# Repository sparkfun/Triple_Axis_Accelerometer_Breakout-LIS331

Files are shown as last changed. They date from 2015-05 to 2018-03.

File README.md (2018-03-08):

SparkFun Triple Axis Accelerometer Breakout - LIS331
========================================

SparkFun Triple Axis Accelerometer Breakout - LIS331

[*SparkFun Triple Axis Accelerometer Breakout - LIS331 (SEN-10345)*](https://www.sparkfun.com/products/10345)

 This is a breakout board for the ultra low-power LIS331HH three axis linear accelerometer. 
 The device has a digital I2C/SPI serial interface which makes it ideal for using in embedded applications. 
 All major pins are broken out to 0.1" spaced headers. It also includes two mounting holes as well.
 
Repository Contents
-------------------

* **/Firmware** - Example code 
* **/Hardware** - Eagle design files (.brd, .sch)
* **/Production** - Production panel files (.brd)

Documentation
--------------
* **[SparkFun Fritzing repo](https://github.com/sparkfun/Fritzing_Parts)** - Fritzing diagrams for SparkFun products.
* **[SparkFun 3D Model repo](https://github.com/sparkfun/3D_Models)** - 3D models of SparkFun products. 
* **[Project Tutorial](https://learn.sparkfun.com/tutorials/raspberry-pi-zero-helmet-impact-force-monitor)** - Project tutorial using the LIS331 on a Raspberry Pi. The code used in the project uses Python and linked in a [different GitHub repository](https://github.com/jenfoxbot/ImpactForceMonitor). 

License Information
-------------------
This product is _**open source**_! 

The **hardware** is released under [Creative Commons ShareAlike 4.0 International](https://creativecommons.org/licenses/by-sa/4.0/).

The **code** is beerware; if you see me (or any other SparkFun employee) at the local, and you've found our code helpful, please buy us a round!

Please use, reuse, and modify these files as you see fit. Please maintain attribution to SparkFun Electronics and release anything derivative under the same license.

Distributed as-is; no warranty is given.

- Your friends at SparkFun.

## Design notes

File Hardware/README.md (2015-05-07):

SparkFun <PRODUCT NAME> Design Files
=====================================

The .sch and .brd files hare are Eagle CAD schematic and PCB design files from SparkFun Electronics.
A freeware version of Eagle can be found [here](http://www.cadsoftusa.com/download-eagle/freeware/). 

License
---------
This product is open source! 
The hardware is released under [Creative Commons ShareAlike 4.0 International](https://creativecommons.org/licenses/by-sa/4.0/).

Please use, reuse, and modify these files as you see fit. Please maintain attribution to SparkFun Electronics and release anything derivative under the same license.

Distributed as-is; no warranty is given.

- Your friends at SparkFun.

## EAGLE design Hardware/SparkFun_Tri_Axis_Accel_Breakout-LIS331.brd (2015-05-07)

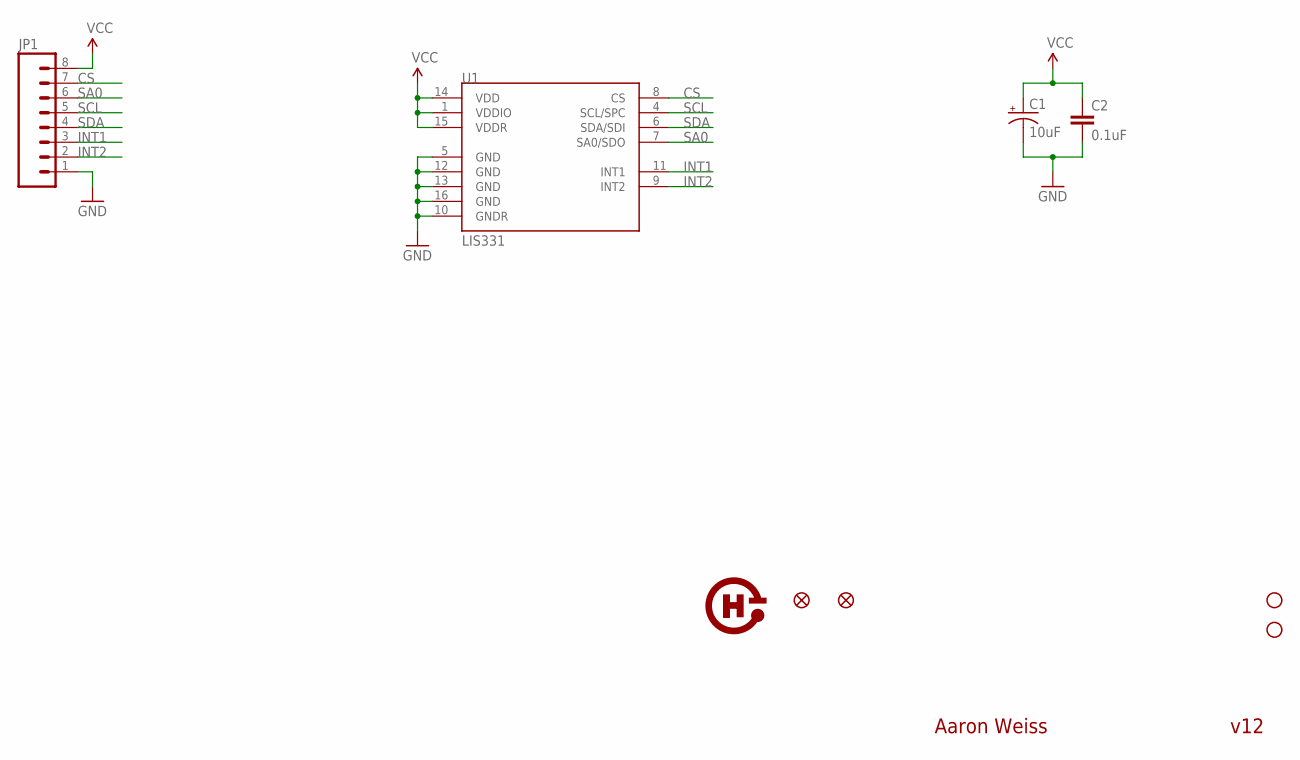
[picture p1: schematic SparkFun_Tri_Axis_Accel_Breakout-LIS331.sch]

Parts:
C1: 10uF; EIA3216
C2: 0.1uF; 0402-CAP
JP1: M08; 1X08
JP3, JP4: STAND-OFF
JP5, JP6: FIDUCIAL1X2; FIDUCIAL-1X2
U1: LIS331; LGA16-3MM
U$1: OSHW-LOGO-SMALL

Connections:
CS: JP1.7, U1.8 (CS)
GND: C1.C (-), C2.2, JP1.1, U1.5 (GND), U1.10 (GNDR), U1.12 (GND), U1.13 (GND), U1.16 (GND)
INT1: JP1.3, U1.11 (INT1)
INT2: JP1.2, U1.9 (INT2)
SA0: JP1.6, U1.7 (SA0/SDO)
SCL: JP1.5, U1.4 (SCL/SPC)
SDA: JP1.4, U1.6 (SDA/SDI)
VCC: C1.A (+), C2.1, JP1.8, U1.1 (VDDIO), U1.14 (VDD), U1.15 (VDDR)

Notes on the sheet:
v12
Aaron Weiss

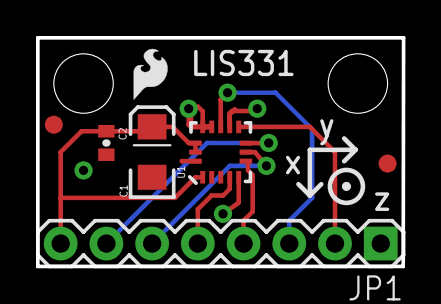
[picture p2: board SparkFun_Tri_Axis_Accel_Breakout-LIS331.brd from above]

Board: 2 copper layers, 20.3 x 12.7 mm, 10 parts (1 on the bottom side), 8 nets.

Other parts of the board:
JP2: LOGO-SFESK; SFE-LOGO-FLAME

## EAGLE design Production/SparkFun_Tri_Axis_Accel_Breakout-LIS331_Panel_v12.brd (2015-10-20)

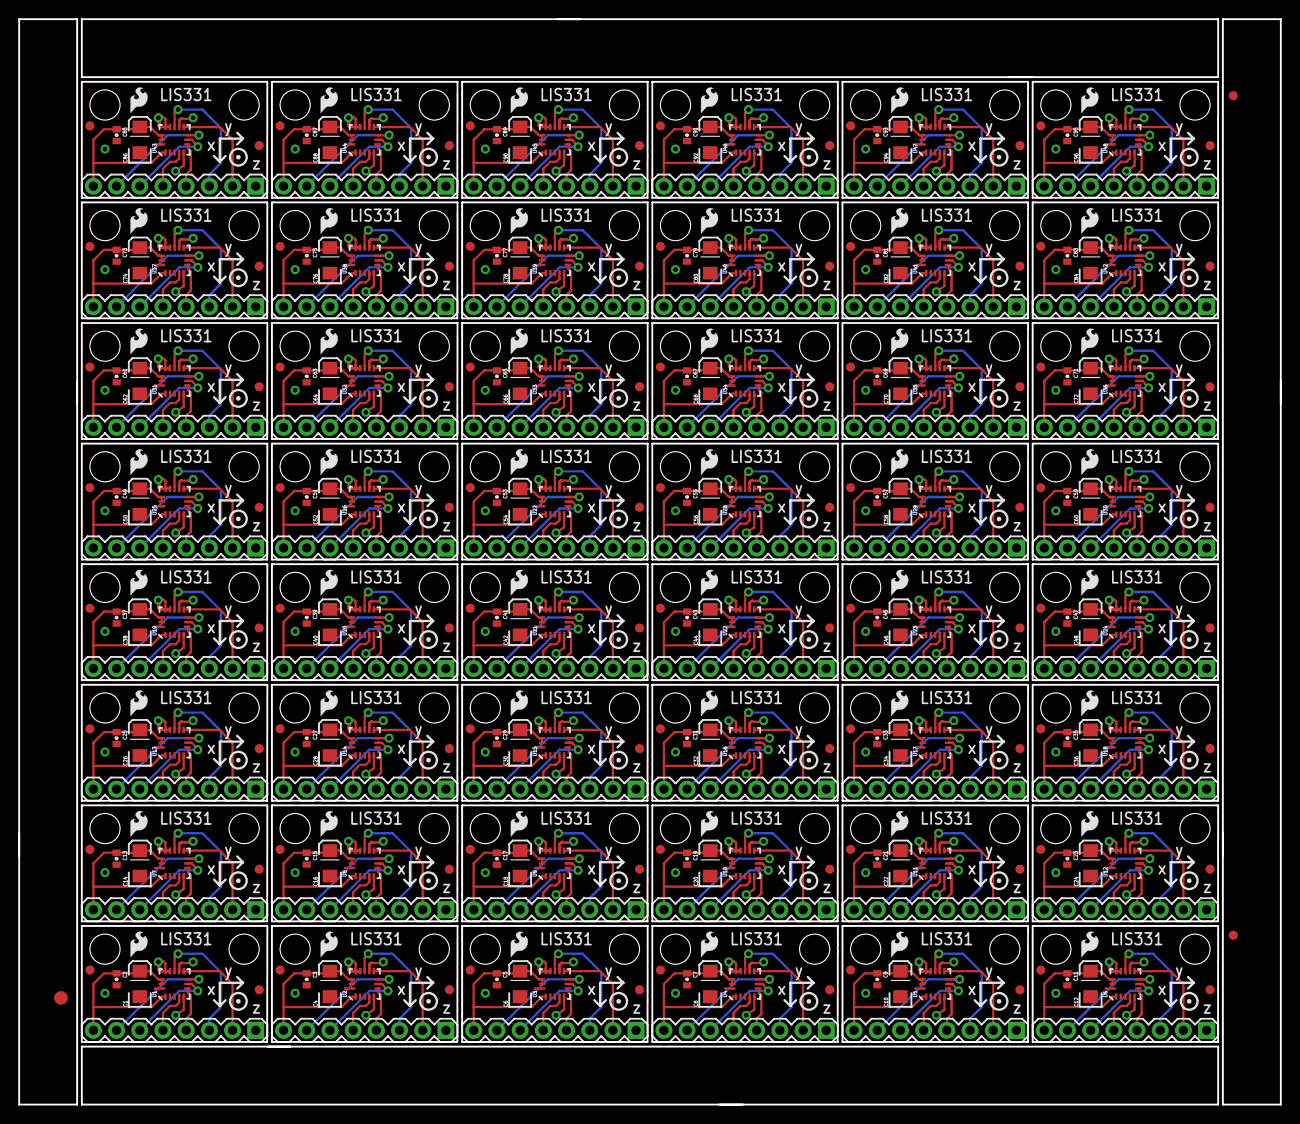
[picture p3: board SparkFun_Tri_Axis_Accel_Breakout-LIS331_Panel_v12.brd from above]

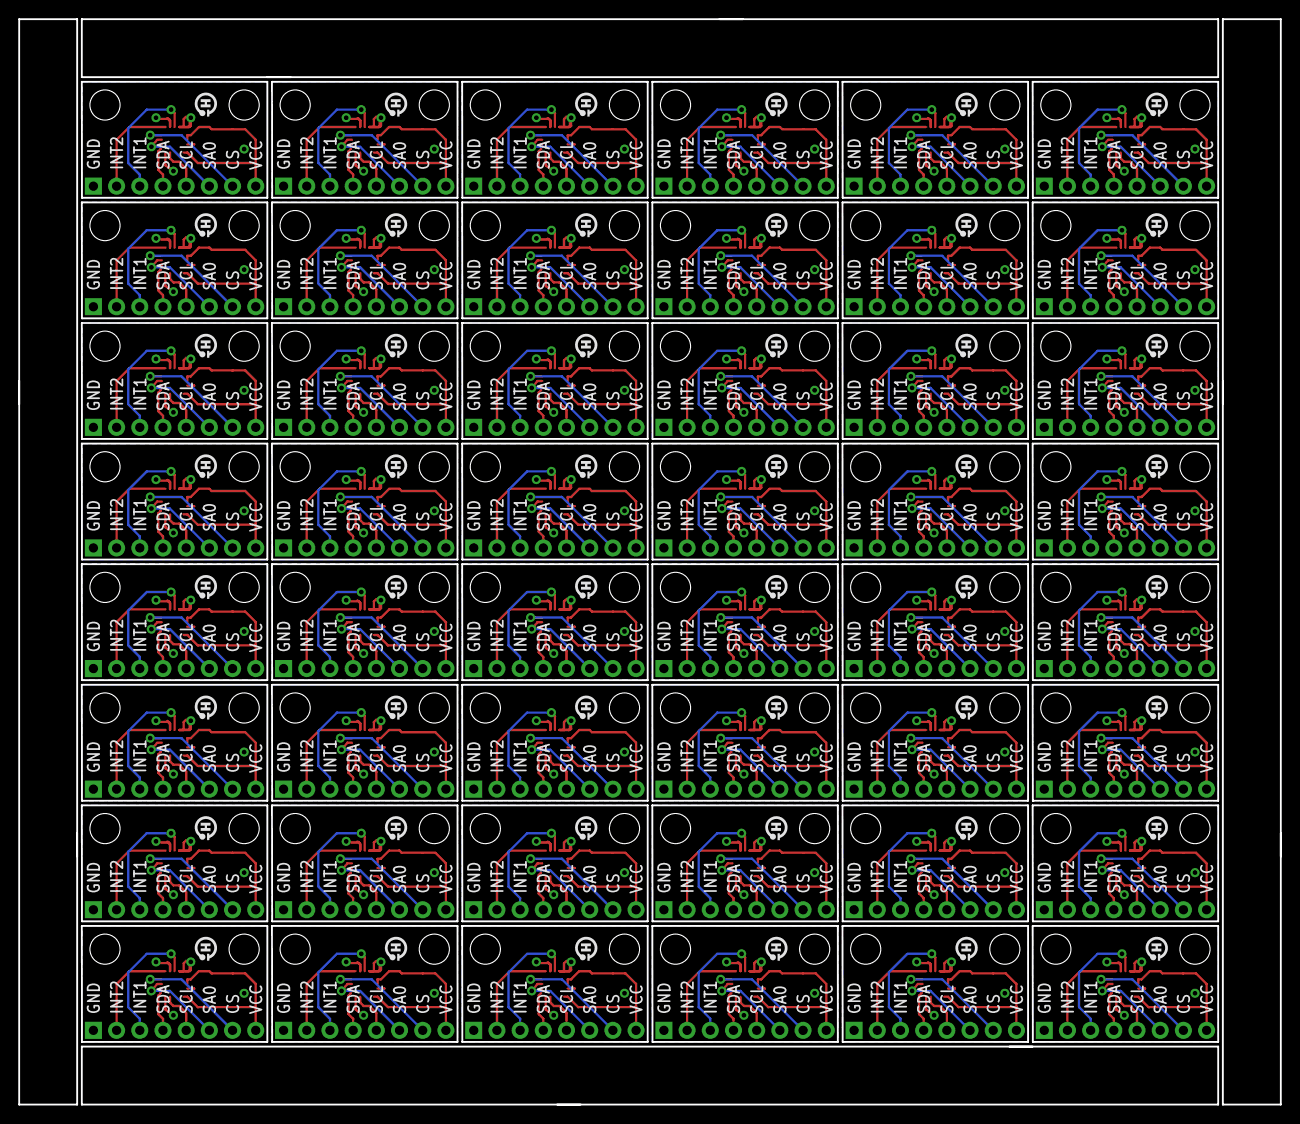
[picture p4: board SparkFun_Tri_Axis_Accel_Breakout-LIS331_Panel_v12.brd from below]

Board: 2 copper layers, 138.2 x 118.9 mm, 483 parts (48 on the bottom side), 384 nets.

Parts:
C1, C4, C6, C8, C10, C12, C14, C16, C18, C20, C22, C24, C26, C28, C30, C32, C34, C36, C38, C40, C42, C44, C46, C48, C50, C52, C54, C56, C58, C60, C62, C64, C66, C68, C70, C72, C74, C76, C78, C80, C82, C84, C86, C88, C90, C92, C94, C96: 10uF; EIA3216
C2, C3, C5, C7, C9, C11, C13, C15, C17, C19, C21, C23, C25, C27, C29, C31, C33, C35, C37, C39, C41, C43, C45, C47, C49, C51, C53, C55, C57, C59, C61, C63, C65, C67, C69, C71, C73, C75, C77, C79, C81, C83, C85, C87, C89, C91, C93, C95: 0.1uF; 0402-CAP
E$1: FIDUCIAL-1.5X3
E$5, E$6: FIDUCIAL-1X2
JP1, JP8, JP14, JP20, JP26, JP32, JP38, JP44, JP50, JP56, JP62, JP68, JP74, JP80, JP86, JP92, JP98, JP104, JP110, JP116, JP122, JP128, JP134, JP140, JP146, JP152, JP158, JP164, JP170, JP176, JP182, JP188, JP194, JP200, JP206, JP212, JP218, JP224, JP230, JP236, JP242, JP248, JP254, JP260, JP266, JP272, JP278, JP284: 1X08
JP2, JP7, JP13, JP19, JP25, JP31, JP37, JP43, JP49, JP55, JP61, JP67, JP73, JP79, JP85, JP91, JP97, JP103, JP109, JP115, JP121, JP127, JP133, JP139, JP145, JP151, JP157, JP163, JP169, JP175, JP181, JP187, JP193, JP199, JP205, JP211, JP217, JP223, JP229, JP235, JP241, JP247, JP253, JP259, JP265, JP271, JP277, JP283: LOGO-SFESK; SFE-LOGO-FLAME
JP3, JP4, JP9, JP10, JP15, JP16, JP21, JP22, JP27, JP28, JP33, JP34, JP39, JP40, JP45, JP46, JP51, JP52, JP57, JP58, JP63, JP64, JP69, JP70, JP75, JP76, JP81, JP82, JP87, JP88, JP93, JP94, JP99, JP100, JP105, JP106, JP111, JP112, JP117, JP118, JP123, JP124, JP129, JP130, JP135, JP136, JP141, JP142, JP147, JP148, JP153, JP154, JP159, JP160, JP165, JP166, JP171, JP172, JP177, JP178, JP183, JP184, JP189, JP190, JP195, JP196, JP201, JP202, JP207, JP208, JP213, JP214, JP219, JP220, JP225, JP226, JP231, JP232, JP237, JP238, JP243, JP244, JP249, JP250, JP255, JP256, JP261, JP262, JP267, JP268, JP273, JP274, JP279, JP280, JP285, JP286: STAND-OFF
JP5, JP6, JP11, JP12, JP17, JP18, JP23, JP24, JP29, JP30, JP35, JP36, JP41, JP42, JP47, JP48, JP53, JP54, JP59, JP60, JP65, JP66, JP71, JP72, JP77, JP78, JP83, JP84, JP89, JP90, JP95, JP96, JP101, JP102, JP107, JP108, JP113, JP114, JP119, JP120, JP125, JP126, JP131, JP132, JP137, JP138, JP143, JP144, JP149, JP150, JP155, JP156, JP161, JP162, JP167, JP168, JP173, JP174, JP179, JP180, JP185, JP186, JP191, JP192, JP197, JP198, JP203, JP204, JP209, JP210, JP215, JP216, JP221, JP222, JP227, JP228, JP233, JP234, JP239, JP240, JP245, JP246, JP251, JP252, JP257, JP258, JP263, JP264, JP269, JP270, JP275, JP276, JP281, JP282, JP287, JP288: FIDUCIAL1X2; FIDUCIAL-1X2
U1, U2, U3, U4, U5, U6, U7, U8, U9, U10, U11, U12, U13, U14, U15, U16, U17, U18, U19, U20, U21, U22, U23, U24, U25, U26, U27, U28, U29, U30, U31, U32, U33, U34, U35, U36, U37, U38, U39, U40, U41, U42, U43, U44, U45, U46, U47, U48: LIS331; LGA16-3MM
U$1, U$2, U$3, U$4, U$5, U$6, U$7, U$8, U$9, U$10, U$11, U$12, U$13, U$14, U$15, U$16, U$17, U$18, U$19, U$20, U$21, U$22, U$23, U$24, U$25, U$26, U$27, U$28, U$29, U$30, U$31, U$32, U$33, U$34, U$35, U$36, U$37, U$38, U$39, U$40, U$41, U$42, U$43, U$44, U$45, U$46, U$47, U$48: OSHW-LOGO-SMALL

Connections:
CS: JP1.7, U1.8
CS1: JP8.7, U2.8
CS2: JP14.7, U3.8
CS3: JP20.7, U4.8
CS4: JP26.7, U5.8
CS5: JP32.7, U6.8
CS6: JP38.7, U7.8
CS7: JP44.7, U8.8
CS8: JP50.7, U9.8
CS9: JP56.7, U10.8
CS10: JP62.7, U11.8
CS11: JP68.7, U12.8
CS12: JP74.7, U13.8
CS13: JP80.7, U14.8
CS14: JP86.7, U15.8
CS15: JP92.7, U16.8
CS16: JP98.7, U17.8
CS17: JP104.7, U18.8
CS18: JP110.7, U19.8
CS19: JP116.7, U20.8
CS20: JP122.7, U21.8
CS21: JP128.7, U22.8
CS22: JP134.7, U23.8
CS23: JP140.7, U24.8
CS24: JP146.7, U25.8
CS25: JP152.7, U26.8
CS26: JP158.7, U27.8
CS27: JP164.7, U28.8
CS28: JP170.7, U29.8
CS29: JP176.7, U30.8
CS30: JP182.7, U31.8
CS31: JP188.7, U32.8
CS32: JP194.7, U33.8
CS33: JP200.7, U34.8
CS34: JP206.7, U35.8
CS35: JP212.7, U36.8
CS36: JP218.7, U37.8
CS37: JP224.7, U38.8
CS38: JP230.7, U39.8
CS39: JP236.7, U40.8
CS40: JP242.7, U41.8
CS41: JP248.7, U42.8
CS42: JP254.7, U43.8
CS43: JP260.7, U44.8
CS44: JP266.7, U45.8
CS45: JP272.7, U46.8
CS46: JP278.7, U47.8
CS47: JP284.7, U48.8
GND: C1.C, C2.2, JP1.1, U1.5, U1.10, U1.12, U1.13, U1.16
GND1: C3.2, C4.C, JP8.1, U2.5, U2.10, U2.12, U2.13, U2.16
GND2: C5.2, C6.C, JP14.1, U3.5, U3.10, U3.12, U3.13, U3.16
GND3: C7.2, C8.C, JP20.1, U4.5, U4.10, U4.12, U4.13, U4.16
GND4: C9.2, C10.C, JP26.1, U5.5, U5.10, U5.12, U5.13, U5.16
GND5: C11.2, C12.C, JP32.1, U6.5, U6.10, U6.12, U6.13, U6.16
GND6: C13.2, C14.C, JP38.1, U7.5, U7.10, U7.12, U7.13, U7.16
GND7: C15.2, C16.C, JP44.1, U8.5, U8.10, U8.12, U8.13, U8.16
GND8: C17.2, C18.C, JP50.1, U9.5, U9.10, U9.12, U9.13, U9.16
GND9: C19.2, C20.C, JP56.1, U10.5, U10.10, U10.12, U10.13, U10.16
GND10: C21.2, C22.C, JP62.1, U11.5, U11.10, U11.12, U11.13, U11.16
GND11: C23.2, C24.C, JP68.1, U12.5, U12.10, U12.12, U12.13, U12.16
GND12: C25.2, C26.C, JP74.1, U13.5, U13.10, U13.12, U13.13, U13.16
GND13: C27.2, C28.C, JP80.1, U14.5, U14.10, U14.12, U14.13, U14.16
GND14: C29.2, C30.C, JP86.1, U15.5, U15.10, U15.12, U15.13, U15.16
GND15: C31.2, C32.C, JP92.1, U16.5, U16.10, U16.12, U16.13, U16.16
GND16: C33.2, C34.C, JP98.1, U17.5, U17.10, U17.12, U17.13, U17.16
GND17: C35.2, C36.C, JP104.1, U18.5, U18.10, U18.12, U18.13, U18.16
GND18: C37.2, C38.C, JP110.1, U19.5, U19.10, U19.12, U19.13, U19.16
GND19: C39.2, C40.C, JP116.1, U20.5, U20.10, U20.12, U20.13, U20.16
GND20: C41.2, C42.C, JP122.1, U21.5, U21.10, U21.12, U21.13, U21.16
GND21: C43.2, C44.C, JP128.1, U22.5, U22.10, U22.12, U22.13, U22.16
GND22: C45.2, C46.C, JP134.1, U23.5, U23.10, U23.12, U23.13, U23.16
GND23: C47.2, C48.C, JP140.1, U24.5, U24.10, U24.12, U24.13, U24.16
GND24: C49.2, C50.C, JP146.1, U25.5, U25.10, U25.12, U25.13, U25.16
GND25: C51.2, C52.C, JP152.1, U26.5, U26.10, U26.12, U26.13, U26.16
GND26: C53.2, C54.C, JP158.1, U27.5, U27.10, U27.12, U27.13, U27.16
GND27: C55.2, C56.C, JP164.1, U28.5, U28.10, U28.12, U28.13, U28.16
GND28: C57.2, C58.C, JP170.1, U29.5, U29.10, U29.12, U29.13, U29.16
GND29: C59.2, C60.C, JP176.1, U30.5, U30.10, U30.12, U30.13, U30.16
GND30: C61.2, C62.C, JP182.1, U31.5, U31.10, U31.12, U31.13, U31.16
GND31: C63.2, C64.C, JP188.1, U32.5, U32.10, U32.12, U32.13, U32.16
GND32: C65.2, C66.C, JP194.1, U33.5, U33.10, U33.12, U33.13, U33.16
GND33: C67.2, C68.C, JP200.1, U34.5, U34.10, U34.12, U34.13, U34.16
GND34: C69.2, C70.C, JP206.1, U35.5, U35.10, U35.12, U35.13, U35.16
GND35: C71.2, C72.C, JP212.1, U36.5, U36.10, U36.12, U36.13, U36.16
GND36: C73.2, C74.C, JP218.1, U37.5, U37.10, U37.12, U37.13, U37.16
GND37: C75.2, C76.C, JP224.1, U38.5, U38.10, U38.12, U38.13, U38.16
GND38: C77.2, C78.C, JP230.1, U39.5, U39.10, U39.12, U39.13, U39.16
GND39: C79.2, C80.C, JP236.1, U40.5, U40.10, U40.12, U40.13, U40.16
GND40: C81.2, C82.C, JP242.1, U41.5, U41.10, U41.12, U41.13, U41.16
GND41: C83.2, C84.C, JP248.1, U42.5, U42.10, U42.12, U42.13, U42.16
GND42: C85.2, C86.C, JP254.1, U43.5, U43.10, U43.12, U43.13, U43.16
GND43: C87.2, C88.C, JP260.1, U44.5, U44.10, U44.12, U44.13, U44.16
GND44: C89.2, C90.C, JP266.1, U45.5, U45.10, U45.12, U45.13, U45.16
GND45: C91.2, C92.C, JP272.1, U46.5, U46.10, U46.12, U46.13, U46.16
GND46: C93.2, C94.C, JP278.1, U47.5, U47.10, U47.12, U47.13, U47.16
GND47: C95.2, C96.C, JP284.1, U48.5, U48.10, U48.12, U48.13, U48.16
INT1: JP1.3, U1.11
INT2: JP1.2, U1.9
INT3: JP8.3, U2.11
INT4: JP8.2, U2.9
INT5: JP14.3, U3.11
INT6: JP14.2, U3.9
INT7: JP20.3, U4.11
INT8: JP20.2, U4.9
INT9: JP26.3, U5.11
INT10: JP26.2, U5.9
INT11: JP32.3, U6.11
INT12: JP32.2, U6.9
INT13: JP38.3, U7.11
INT14: JP38.2, U7.9
INT15: JP44.3, U8.11
INT16: JP44.2, U8.9
INT17: JP50.3, U9.11
INT18: JP50.2, U9.9
INT19: JP56.3, U10.11
INT20: JP56.2, U10.9
INT21: JP62.3, U11.11
INT22: JP62.2, U11.9
INT23: JP68.3, U12.11
INT24: JP68.2, U12.9
INT25: JP74.3, U13.11
INT26: JP74.2, U13.9
INT27: JP80.3, U14.11
INT28: JP80.2, U14.9
INT29: JP86.3, U15.11
INT30: JP86.2, U15.9
INT31: JP92.3, U16.11
INT32: JP92.2, U16.9
INT33: JP98.3, U17.11
INT34: JP98.2, U17.9
INT35: JP104.3, U18.11
INT36: JP104.2, U18.9
INT37: JP110.3, U19.11
INT38: JP110.2, U19.9
INT39: JP116.3, U20.11
INT40: JP116.2, U20.9
INT41: JP122.3, U21.11
INT42: JP122.2, U21.9
INT43: JP128.3, U22.11
INT44: JP128.2, U22.9
INT45: JP134.3, U23.11
INT46: JP134.2, U23.9
INT47: JP140.3, U24.11
INT48: JP140.2, U24.9
INT49: JP146.3, U25.11
INT50: JP146.2, U25.9
INT51: JP152.3, U26.11
INT52: JP152.2, U26.9
INT53: JP158.3, U27.11
INT54: JP158.2, U27.9
INT55: JP164.3, U28.11
INT56: JP164.2, U28.9
INT57: JP170.3, U29.11
INT58: JP170.2, U29.9
INT59: JP176.3, U30.11
INT60: JP176.2, U30.9
INT61: JP182.3, U31.11
INT62: JP182.2, U31.9
INT63: JP188.3, U32.11
INT64: JP188.2, U32.9
INT65: JP194.3, U33.11
INT66: JP194.2, U33.9
INT67: JP200.3, U34.11
INT68: JP200.2, U34.9
INT69: JP206.3, U35.11
INT70: JP206.2, U35.9
INT71: JP212.3, U36.11
INT72: JP212.2, U36.9
INT73: JP218.3, U37.11
INT74: JP218.2, U37.9
INT75: JP224.3, U38.11
INT76: JP224.2, U38.9
INT77: JP230.3, U39.11
INT78: JP230.2, U39.9
INT79: JP236.3, U40.11
INT80: JP236.2, U40.9
INT81: JP242.3, U41.11
INT82: JP242.2, U41.9
INT83: JP248.3, U42.11
INT84: JP248.2, U42.9
INT85: JP254.3, U43.11
INT86: JP254.2, U43.9
INT87: JP260.3, U44.11
INT88: JP260.2, U44.9
INT89: JP266.3, U45.11
INT90: JP266.2, U45.9
INT91: JP272.3, U46.11
INT92: JP272.2, U46.9
INT93: JP278.3, U47.11
INT94: JP278.2, U47.9
INT95: JP284.3, U48.11
INT96: JP284.2, U48.9
SA0: JP1.6, U1.7
SA1: JP8.6, U2.7
SA2: JP14.6, U3.7
SA3: JP20.6, U4.7
SA4: JP26.6, U5.7
SA5: JP32.6, U6.7
SA6: JP38.6, U7.7
SA7: JP44.6, U8.7
SA8: JP50.6, U9.7
SA9: JP56.6, U10.7
SA10: JP62.6, U11.7
SA11: JP68.6, U12.7
SA12: JP74.6, U13.7
SA13: JP80.6, U14.7
SA14: JP86.6, U15.7
SA15: JP92.6, U16.7
SA16: JP98.6, U17.7
SA17: JP104.6, U18.7
SA18: JP110.6, U19.7
SA19: JP116.6, U20.7
SA20: JP122.6, U21.7
SA21: JP128.6, U22.7
SA22: JP134.6, U23.7
SA23: JP140.6, U24.7
SA24: JP146.6, U25.7
SA25: JP152.6, U26.7
SA26: JP158.6, U27.7
SA27: JP164.6, U28.7
SA28: JP170.6, U29.7
SA29: JP176.6, U30.7
SA30: JP182.6, U31.7
SA31: JP188.6, U32.7
SA32: JP194.6, U33.7
SA33: JP200.6, U34.7
SA34: JP206.6, U35.7
SA35: JP212.6, U36.7
SA36: JP218.6, U37.7
SA37: JP224.6, U38.7
SA38: JP230.6, U39.7
SA39: JP236.6, U40.7
SA40: JP242.6, U41.7
SA41: JP248.6, U42.7
SA42: JP254.6, U43.7
SA43: JP260.6, U44.7
SA44: JP266.6, U45.7
SA45: JP272.6, U46.7
SA46: JP278.6, U47.7
SA47: JP284.6, U48.7
SCL: JP1.5, U1.4
SCL1: JP8.5, U2.4
SCL2: JP14.5, U3.4
SCL3: JP20.5, U4.4
SCL4: JP26.5, U5.4
SCL5: JP32.5, U6.4
SCL6: JP38.5, U7.4
SCL7: JP44.5, U8.4
SCL8: JP50.5, U9.4
SCL9: JP56.5, U10.4
SCL10: JP62.5, U11.4
SCL11: JP68.5, U12.4
SCL12: JP74.5, U13.4
SCL13: JP80.5, U14.4
SCL14: JP86.5, U15.4
SCL15: JP92.5, U16.4
SCL16: JP98.5, U17.4
SCL17: JP104.5, U18.4
SCL18: JP110.5, U19.4
SCL19: JP116.5, U20.4
SCL20: JP122.5, U21.4
SCL21: JP128.5, U22.4
SCL22: JP134.5, U23.4
SCL23: JP140.5, U24.4
SCL24: JP146.5, U25.4
SCL25: JP152.5, U26.4
SCL26: JP158.5, U27.4
SCL27: JP164.5, U28.4
SCL28: JP170.5, U29.4
SCL29: JP176.5, U30.4
SCL30: JP182.5, U31.4
SCL31: JP188.5, U32.4
SCL32: JP194.5, U33.4
SCL33: JP200.5, U34.4
SCL34: JP206.5, U35.4
SCL35: JP212.5, U36.4
SCL36: JP218.5, U37.4
SCL37: JP224.5, U38.4
SCL38: JP230.5, U39.4
SCL39: JP236.5, U40.4
SCL40: JP242.5, U41.4
SCL41: JP248.5, U42.4
SCL42: JP254.5, U43.4
SCL43: JP260.5, U44.4
SCL44: JP266.5, U45.4
SCL45: JP272.5, U46.4
SCL46: JP278.5, U47.4
SCL47: JP284.5, U48.4
SDA: JP1.4, U1.6
SDA1: JP8.4, U2.6
SDA2: JP14.4, U3.6
SDA3: JP20.4, U4.6
SDA4: JP26.4, U5.6
SDA5: JP32.4, U6.6
SDA6: JP38.4, U7.6
SDA7: JP44.4, U8.6
SDA8: JP50.4, U9.6
SDA9: JP56.4, U10.6
SDA10: JP62.4, U11.6
SDA11: JP68.4, U12.6
SDA12: JP74.4, U13.6
SDA13: JP80.4, U14.6
SDA14: JP86.4, U15.6
SDA15: JP92.4, U16.6
SDA16: JP98.4, U17.6
SDA17: JP104.4, U18.6
SDA18: JP110.4, U19.6
SDA19: JP116.4, U20.6
SDA20: JP122.4, U21.6
SDA21: JP128.4, U22.6
SDA22: JP134.4, U23.6
SDA23: JP140.4, U24.6
SDA24: JP146.4, U25.6
SDA25: JP152.4, U26.6
SDA26: JP158.4, U27.6
SDA27: JP164.4, U28.6
SDA28: JP170.4, U29.6
SDA29: JP176.4, U30.6
SDA30: JP182.4, U31.6
SDA31: JP188.4, U32.6
SDA32: JP194.4, U33.6
SDA33: JP200.4, U34.6
SDA34: JP206.4, U35.6
SDA35: JP212.4, U36.6
SDA36: JP218.4, U37.6
SDA37: JP224.4, U38.6
SDA38: JP230.4, U39.6
SDA39: JP236.4, U40.6
SDA40: JP242.4, U41.6
SDA41: JP248.4, U42.6
SDA42: JP254.4, U43.6
SDA43: JP260.4, U44.6
SDA44: JP266.4, U45.6
SDA45: JP272.4, U46.6
SDA46: JP278.4, U47.6
SDA47: JP284.4, U48.6
VCC: C1.A, C2.1, JP1.8, U1.1, U1.14, U1.15
VCC1: C3.1, C4.A, JP8.8, U2.1, U2.14, U2.15
VCC2: C5.1, C6.A, JP14.8, U3.1, U3.14, U3.15
VCC3: C7.1, C8.A, JP20.8, U4.1, U4.14, U4.15
VCC4: C9.1, C10.A, JP26.8, U5.1, U5.14, U5.15
VCC5: C11.1, C12.A, JP32.8, U6.1, U6.14, U6.15
VCC6: C13.1, C14.A, JP38.8, U7.1, U7.14, U7.15
VCC7: C15.1, C16.A, JP44.8, U8.1, U8.14, U8.15
VCC8: C17.1, C18.A, JP50.8, U9.1, U9.14, U9.15
VCC9: C19.1, C20.A, JP56.8, U10.1, U10.14, U10.15
VCC10: C21.1, C22.A, JP62.8, U11.1, U11.14, U11.15
VCC11: C23.1, C24.A, JP68.8, U12.1, U12.14, U12.15
VCC12: C25.1, C26.A, JP74.8, U13.1, U13.14, U13.15
VCC13: C27.1, C28.A, JP80.8, U14.1, U14.14, U14.15
VCC14: C29.1, C30.A, JP86.8, U15.1, U15.14, U15.15
VCC15: C31.1, C32.A, JP92.8, U16.1, U16.14, U16.15
VCC16: C33.1, C34.A, JP98.8, U17.1, U17.14, U17.15
VCC17: C35.1, C36.A, JP104.8, U18.1, U18.14, U18.15
VCC18: C37.1, C38.A, JP110.8, U19.1, U19.14, U19.15
VCC19: C39.1, C40.A, JP116.8, U20.1, U20.14, U20.15
VCC20: C41.1, C42.A, JP122.8, U21.1, U21.14, U21.15
VCC21: C43.1, C44.A, JP128.8, U22.1, U22.14, U22.15
VCC22: C45.1, C46.A, JP134.8, U23.1, U23.14, U23.15
VCC23: C47.1, C48.A, JP140.8, U24.1, U24.14, U24.15
VCC24: C49.1, C50.A, JP146.8, U25.1, U25.14, U25.15
VCC25: C51.1, C52.A, JP152.8, U26.1, U26.14, U26.15
VCC26: C53.1, C54.A, JP158.8, U27.1, U27.14, U27.15
VCC27: C55.1, C56.A, JP164.8, U28.1, U28.14, U28.15
VCC28: C57.1, C58.A, JP170.8, U29.1, U29.14, U29.15
VCC29: C59.1, C60.A, JP176.8, U30.1, U30.14, U30.15
VCC30: C61.1, C62.A, JP182.8, U31.1, U31.14, U31.15
VCC31: C63.1, C64.A, JP188.8, U32.1, U32.14, U32.15
VCC32: C65.1, C66.A, JP194.8, U33.1, U33.14, U33.15
VCC33: C67.1, C68.A, JP200.8, U34.1, U34.14, U34.15
VCC34: C69.1, C70.A, JP206.8, U35.1, U35.14, U35.15
VCC35: C71.1, C72.A, JP212.8, U36.1, U36.14, U36.15
VCC36: C73.1, C74.A, JP218.8, U37.1, U37.14, U37.15
VCC37: C75.1, C76.A, JP224.8, U38.1, U38.14, U38.15
VCC38: C77.1, C78.A, JP230.8, U39.1, U39.14, U39.15
VCC39: C79.1, C80.A, JP236.8, U40.1, U40.14, U40.15
VCC40: C81.1, C82.A, JP242.8, U41.1, U41.14, U41.15
VCC41: C83.1, C84.A, JP248.8, U42.1, U42.14, U42.15
VCC42: C85.1, C86.A, JP254.8, U43.1, U43.14, U43.15
VCC43: C87.1, C88.A, JP260.8, U44.1, U44.14, U44.15
VCC44: C89.1, C90.A, JP266.8, U45.1, U45.14, U45.15
VCC45: C91.1, C92.A, JP272.8, U46.1, U46.14, U46.15
VCC46: C93.1, C94.A, JP278.8, U47.1, U47.14, U47.15
VCC47: C95.1, C96.A, JP284.8, U48.1, U48.14, U48.15

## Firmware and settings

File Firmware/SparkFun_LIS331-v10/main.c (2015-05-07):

/*
    3-21-11
    Aaron Weiss, aaron at sparkfun dot com
	
	License: Creative Commons Attribution Share-Alike 3.0
	http://creativecommons.org/licenses/by-sa/3.0
	
	v10 Example
	-outputs x,y,z acceleration values every 1 ms
	-output is driven by a timer overflow interrupt, this allows the user to
	 more easily add additional code without messing with the timing
	-values are in g's
	
	LIS331 Accelerometer Configuration: 
	4-wire SPI, normal mode, 400Hz 
	
	Hardware:
	Atmega328p, 3.3V, ext. 8MHz, 38400 baud
	
	Hardware Conections (LIS to Arduino):
	
	LIS331   |   Arduino
	---------------------
	  VCC    |    VCC (3.3V)
	  CS     |    pin 10 (PB2)
	  SCL    |    pin 13 (PB5)
	  SA0    |    pin 12 (PB4)
	  SDA    |    pin 11 (PB3)
	  GND    |    pin GND
	
	Note: if you need a higher sampling frequency, you need to run a higher clock,
		  INT functionality not used
*/

#include <stdlib.h>
#include <stdio.h>
#include <avr/io.h>
#include <avr/pgmspace.h>
#include <avr/interrupt.h>

#define MYUBRR 12  //8MHz, 38400bps 

#define sbi(var, mask)   ((var) |= (uint8_t)(1 << mask))
#define cbi(var, mask)   ((var) &= (uint8_t)~(1 << mask))

#define MOSI    3  //PORTB
#define MISO    4  //PORTB
#define SCK     5  //PORTB
#define CS		2  //PORTB

#define SCALE 0.0007324  //sets g-level (48 fullscale range)/(2^16bits) = SCALE

///============Initialize Prototypes=====================///////////////////////
void ioinit(void);      // initializes IO
void UART_Init(unsigned int ubrr);
static int uart_putchar(char c, FILE *stream);
uint8_t uart_getchar(void);
static FILE mystdout = FDEV_SETUP_STREAM(uart_putchar, NULL, _FDEV_SETUP_WRITE);
void delay(uint16_t x); // general purpose delay

/////======SPI functions=================================////////////////////////
void SPI_MasterInit(void);
void SPI_MasterTransmit(uint8_t address);

/////======Main Prototypes================================////////////////////////
void config(void);
uint8_t read(uint8_t addr);
void accel(void);

///===========Global Vars=============================//////////////////////////
volatile double xaccel, yaccel, zaccel;

//=========MAIN================/////////////////////////////////////////////////
ISR(TIMER1_OVF_vect)
{
	//every ms the acceleration values are printed
	TCNT1 = 55536;//(8/8MHz)*(65536bits-55536)=0.01s
	accel(); //update LIS registers
	printf("x=%6.2f,", xaccel);
	printf("y=%6.2f,", yaccel);
	printf("z=%6.2f\n\r", zaccel);
}

int main(void)
{	
	ioinit(); //Setup IO pins and defaults
	SPI_MasterInit();
	config();
	
	while(1)
	{	
		//put your code here
	}
	return (0);
}

void config(void)
{
	cbi(PORTB, CS);
	delay(1);
	SPI_MasterTransmit(0x20); //write to 0x20
	SPI_MasterTransmit(0x37); //normal mode, 400Hz, xyz-enabled
	delay(1);
	sbi(PORTB, CS);
	
	delay(100);
	
	cbi(PORTB, CS);
	delay(1);
	SPI_MasterTransmit(0x21); //write to 0x21
	SPI_MasterTransmit(0x00); //HP filter ON (cuttoff@8MHz) = 0x60, HPfilter OFF = 0x00
	delay(1);
	sbi(PORTB, CS);
	
	delay(100);
	
	cbi(PORTB, CS);
	delay(1);
	SPI_MasterTransmit(0x23); //write to 0x23
	SPI_MasterTransmit(0x30); //24g 
	delay(1);
	sbi(PORTB, CS);
}

//usage: read('hex address'), e.g. read(0x20), reads CTRL_REG1
//returns the value in the address, e.g. read(0x20) = 0x07, returns the default value of 0x20 
uint8_t read(uint8_t addr)
{
	uint8_t regbyte;
	uint8_t read = 0;
	read |= (1<<7); 
	uint8_t byte = 0;
	byte = read | addr;
	
	cbi(PORTB, CS);
	delay(1);
	SPI_MasterTransmit(byte);
	SPI_MasterTransmit(0x00); //must keep clock moving, so tx another byte
	regbyte = SPDR;
	delay(1);
	sbi(PORTB, CS);
	
	return(regbyte);
}

void accel(void)
{	
	uint16_t xl, xh, yl, yh, zl, zh;
	int16_t tempx, tempy, tempz;
	
	cbi(PORTB, CS);
	SPI_MasterTransmit(0xe8); //read bit | consecutive measure bit | 0x28 = 0xe8
	SPI_MasterTransmit(0x00); //must keep clock moving, so tx another byte
	xl = SPDR;
	SPI_MasterTransmit(0x00); //must keep clock moving, so tx another byte
	xh = SPDR;
	SPI_MasterTransmit(0x00); //must keep clock moving, so tx another byte
	yl = SPDR;
	SPI_MasterTransmit(0x00); //must keep clock moving, so tx another byte
	yh = SPDR;
	SPI_MasterTransmit(0x00); //must keep clock moving, so tx another byte
	zl = SPDR;
	SPI_MasterTransmit(0x00); //must keep clock moving, so tx another byte
	zh = SPDR;
	sbi(PORTB, CS);
	
	tempx = (xl|(xh << 8)); //concatenate low and high bits together, load into signed 16 bit
	xaccel = SCALE*tempx;    //multiply by scale factor for g-level
	tempy = (yl|(yh << 8));
	yaccel = SCALE*tempy;
	tempz = (zl|(zh << 8));
	zaccel = SCALE*tempz;
}
////////////////////////////////////////////////////////////////////////////////
///==============Initializations=======================================/////////
////////////////////////////////////////////////////////////////////////////////
void ioinit (void)
{
    //1 = output, 0 = input
    DDRB = 0b11101111; //input on PB4 = MISO 
    DDRD = 0b11110010; //PORTD (RX on PD0)
	
	sbi(PORTB, CS);
    UART_Init(MYUBRR);
	
	// Setting Timer 1
	// normal mode
	TCCR1A = 0x00;
	// Set to clk/8 
	TCCR1B |= (1<<CS11);
	//enable overflow interrupt
	TIMSK1 |= (1<<TOIE1);
	//load timer with a value to optimize for 1 second,
	TCNT1 = 55536;	//(8/8MHz)*(65536bits-55536)=0.01s
	
	sei(); //turn on global interrupts and enable timer
}

void UART_Init(unsigned int ubrr)
{
	int ubrr_new;
	// set baud rate
	ubrr_new = ubrr;
	UBRR0H = ubrr_new>>8;
	UBRR0L = ubrr_new;

	// Enable receiver and transmitter
	UCSR0A = (0<<U2X0); //double UART speed
	UCSR0B = (1<<RXEN0)|(1<<TXEN0);

	// Set frame format: 8 bit, no parity, 1 stop bit,
	UCSR0C = (1<<UCSZ00)|(1<<UCSZ01);

	stdout = &mystdout; //Required for printf init
}

static int uart_putchar(char c, FILE *stream)
{
    if (c == '\n') uart_putchar('\r', stream);
  
    loop_until_bit_is_set(UCSR0A, UDRE0);
    UDR0 = c;
    
    return 0;
}

uint8_t uart_getchar(void)
{
    while( !(UCSR0A & (1<<RXC0)) );
    return(UDR0);
}
//General short delays
void delay(uint16_t x)
{
  uint8_t y;
  for ( ; x > 100 ; x--){
    for ( y = 0 ; y < 200 ; y++){ 
    asm volatile ("nop");
    }
  }
}
//==========================//
//
//SPI functions
//
//==========================//
void SPI_MasterInit(void)
{
	DDRB = (1<<DDB3)|(1<<DDB5)|(1<<DDB2)|(1<<DDB1);
	SPCR = (1<<SPE)|(1<<MSTR)|(1<<CPOL)|(1<<CPHA);
}

void SPI_MasterTransmit(uint8_t address)
{
	SPDR = address;
	while(!(SPSR & (1<<SPIF)));
}

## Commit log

2015-05-07 Adding hardware files, example code
    [SparkFun_Tri_Axis_Accel_Breakout-LIS331.brd, SparkFun_Tri_Axis_Accel_Breakout-LIS331.sch]
2015-10-20 created new v12 panel
    [SparkFun_Tri_Axis_Accel_Breakout-LIS331_Panel_v12.brd]

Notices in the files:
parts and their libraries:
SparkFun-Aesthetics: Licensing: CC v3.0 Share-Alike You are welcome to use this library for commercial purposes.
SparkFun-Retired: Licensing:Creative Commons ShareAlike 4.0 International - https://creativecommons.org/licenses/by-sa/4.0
